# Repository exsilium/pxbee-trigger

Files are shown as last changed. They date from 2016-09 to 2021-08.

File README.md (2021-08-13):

# pxbee-trigger

Programmable XBee Trigger that is ZigBee Home Automation profile compliant. Possible to integrate with [SmartThings](https://www.smartthings.com) Hub v3 or a separate ZigBee / XBee network. Includes a reference hardware design up to 4 channels with a full BOM, perfect for DIYselfers out there.

Used in real life to automate garage / gate automatons.

## Hardware example

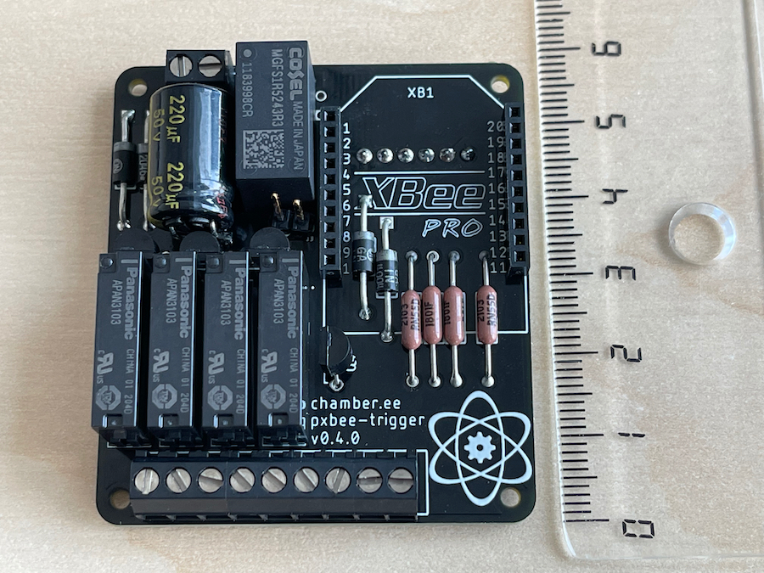
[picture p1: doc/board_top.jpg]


An assembled board without a mounted XBee radio. Metric scale for reference (cm.). Board dimension - 51 x 57 mm.
## Bill of Materials (BOM)

| Designator  | Component | Manufacturer | Quantity | SKU / Part nr. | Spec | Option |
| --- | --- | --- | --- | --- | --- | --- |
| XB1 | [Programmable XBee](https://www.digi.com/products/xbee-rf-solutions/rf-modules/xbee-zigbee#partnumbers) (with RPSMA) | [Digi](https://www.digi.com) | 1 | XBP24CZ7SITB003 | [PDF](http://www.digi.com/resources/documentation/digidocs/pdfs/90002002.pdf) | |
| BR1 | [Bridge Rectifier DF01M](https://www.mouser.ee/ProductDetail/512-DF01M) | [ON Semiconductor](https://www.onsemi.com) | 1 | Mouser No: 512-DF01M | [PDF](https://www.mouser.ee/datasheet/2/308/DF10M-D-1803766.pdf) | |
| C1 (C2) | [Electrolytic Capacitor - Radial 220uF 50V](https://www.mouser.ee/ProductDetail/EEU-FM1H221) | [Panasonic](https://industrial.panasonic.com). | 1-2 | Mouser No: 667-EEU-FM1H221. | [PDF](https://www.mouser.ee/datasheet/2/315/ABA0000C1018-947496.pdf). | |
| PS1 | [DC/DC Isolated Converter Cosel MGFS1R5243R3](https://www.mouser.ee/ProductDetail/436-MGFS1R5243R3) | [Cosel](https://www.coseleurope.eu) | 1 | Mouser No: 436-MGFS1R5243R3 | [PDF](https://www.mouser.ee/datasheet/2/622/SFE_MGFS-1115632.pdf) | |
| Q1,Q2,Q3,Q4 | [Bipolar Transistor BC548BTA](https://www.mouser.ee/ProductDetail/512-BC548BTA) | [ON Semiconductor](https://www.onsemi.com) | 4 | Mouser No: 512-BC548BTA | [PDF](https://www.mouser.ee/datasheet/2/308/BC548-1118644.pdf) | |
| D1,D2,D3,D4 | [Diode 1N4004](https://www.mouser.ee/ProductDetail/863-1N4004RLG) | [ON Semiconductor](https://www.onsemi.com) | 4 | Mouser No: 863-1N4004RLG | [PDF](https://www.mouser.ee/datasheet/2/308/1N4001-D-110363.pdf) | |
| K1,K2,K3,K4 | [General Purpose Relay (APAN3103)](https://www.mouser.ee/ProductDetail/769-APAN3103) | [Panasonic](https://industrial.panasonic.com) | 4 | Mouser No: 769-APAN3103 | [PDF](https://www.mouser.ee/datasheet/2/315/mech_eng_pan-1299258.pdf) | |
| R1,R2,R3,R4 | [Resistor RN55D1801FB14](https://www.mouser.ee/ProductDetail/71-RN55D1801FB14) | [Vishay](https://www.vishay.com) | 4 | Mouser No: 71-RN55D1801FB14 | [PDF](https://www.mouser.ee/datasheet/2/427/cmfmil-109690.pdf) | |
| XB1 | [10 pin header for XBee](https://www.mouser.ee/ProductDetail/855-M22-7131042) | [Harwin](https://www.harwin.com) | 2 | Mouser No: 855-M22-7131042 | [PDF](https://www.mouser.ee/datasheet/2/181/M22-713-1134021.pdf) | |
| J1 | [2 pin Terminal Block (PCB)](https://www.mouser.ee/ProductDetail/538-39501-1002) | [Molex](https://www.molex.com) | 1 | Mouser No: 538-39501-1002 | [PDF](https://www.mouser.ee/datasheet/2/276/0395011002_TERMINAL_BLOCKS-163759.pdf) | A |
| | [2 pin Terminal Plug](https://www.mouser.ee/ProductDetail/538-39500-0002) | [Molex](https://www.molex.com) | 1 | Mouser No: 538-39500-0002 | [PDF](https://www.mouser.ee/datasheet/2/276/0395000002_TERMINAL_BLOCKS-136229.pdf) | A |
| J2 | [9 pin Terminal Block (PCB)](https://www.mouser.ee/ProductDetail/538-39501-1009) | [Molex](https://www.molex.com) | 1 | Mouser No: 538-39501-1009 | [PDF](https://www.mouser.ee/datasheet/2/276/0395011009_TERMINAL_BLOCKS-163629.pdf) | A |
| | [9 pin Terminal Plug](https://www.mouser.ee/ProductDetail/651-1908101) | [Molex](https://www.molex.com) | 1 | Mouser No: 651-1908101 | [PDF](https://www.mouser.ee/datasheet/2/276/0395000009_TERMINAL_BLOCKS-163669.pdf) | A |
| J1 | [2 pin Fixed Terminal Block (PCB)](https://www.mouser.ee/ProductDetail/538-39357-0002) | [Molex](https://www.molex.com) | 1 | Mouser No: 538-39357-0002 | [PDF](https://www.mouser.ee/datasheet/2/276/0393570002_TERMINAL_BLOCKS-227759.pdf) | B |
| J2 | [9 pin Fixed Terminal Block (PCB)](https://www.mouser.ee/ProductDetail/538-39357-0009) | [Molex](https://www.molex.com) | 1 | Mouser No: 538-39357-0009 | [PDF](https://www.mouser.ee/datasheet/2/276/0393570009_TERMINAL_BLOCKS-136250.pdf) | B |
| | [Antenna with RP-SMA Connector](https://www.mouser.ee/ProductDetail/712-ANT-2.4-CW-RAH) | [Linx Technologies](https://linxtechnologies.com) | 1 | Mouser No: 712-ANT-2.4-CW-RAH | [PDF](https://www.mouser.ee/datasheet/2/238/ant-2.4-cw-rah-ccc-1659143.pdf) | |
| JP1 | [6 pin Debug Header](https://www.mouser.ee/ProductDetail/538-22-28-8065) | [Molex](https://www.molex.com) | 1 | Mouser No: 538-22-28-8065 | [PDF](https://www.mouser.ee/datasheet/2/276/0022288065_PCB_HEADERS-159204.pdf) | O |
| J3 | [2 pin Reset Header](https://www.mouser.ee/ProductDetail/Molex/22-28-5027) | [Molex](https://www.molex.com) | 1 | Mouser No: 538-22-28-5027 | [PDF](https://www.mouser.ee/ProductDetail/Molex/22-28-5027) | O |

Standard 3.5 width headers are used. Option **A**) uses pluggable termination; **B**) Fixed screw termination; **O**) Parts are optional and meant for development; Components can easily be switched with other termination blocks or use direct wire soldering.

## Compiling

- On 32bit Linux target, simply: `make`
- On 64bit Linux target:
    - Intall 32bit compatible libraries: `sudo apt-get install lib32stdc++6`
    - `make`
- On MacOS:
    - Install [Docker](https://www.docker.com)
    - `make builddocker`
    - `make dall`

## Firmware

- Output file: `obj/trigger.abs.bin`
- Upload the file via local XMODEM or use Over-the-air upgrade if the current firmware supports it (you can use [pxbee-fwup.js](https://github.com/exsilium/pxbee-fwup.js))
- See further [Programmable XBee documentation](http://xbee-sdk-doc.readthedocs.io)

## Trigger

Send a Unicast ZCL "On" command to trigger the connected relay for 125ms (Relay 1). The state of the switch remains in "Off" state. Broadcast command is ignored by default.

```
Endpoint: 0xEA,
clusterId: 0x0006,
profileId: 0x0104,
command: 0x01
```

## Settings

The following defines can be altered in `custom.h` prior to compilation to change the behavior how the Trigger works:

|  Name | Description | Default |
| ---| --- | --- |
| `PXBEE_TRIGGER_IGNORE_BROADCAST` | When enabled, ignores broadcast commands and reacts only when unicast messages are sent to the specific address (ignores All On/All Off commands). | Enabled |
| `ZCL_MANUFACTURER` | The reported manufacturer string. For SmartThings local execution support without custom device handler, set this to "Leviton". | "PXBee" |
| `ZCL_MODEL` | The reported model string. For SmartThings local execution support without custom device handler, set this to "ZSS-10". | "Trigger" |

### Endpoints

|  Endpoint | Description |
| ---| --- |
| `0xEA` | Relay 1 |
| `0xEB` | Relay 2 |
| `0xEC` | Relay 3 |
| `0xED` | Relay 4 |
| `0xEE` | Auxiliary binary input endpoint |

## License

This project is based on [exsilium/pxbee-blink-led](https://github.com/exsilium/pxbee-blink-led) boilerplate and includes the full [Digi](http://www.digi.com) XBee SDK version 1.6.0 sources.

Includes the necessary build binaries:
```
HI-CROSS+ ANSI-C Compiler for HC08 V-5.0.39, Dec 13 2011
HI-CROSS+ SmartLinker V-5.0.48, Dec 13 2011
HI-CROSS+ Burner V-5.0.16, Dec 13 2011
(c) Copyright Freescale 1987-2010
```

If not otherwise noted, the added code is [BSD licensed](LICENSE).

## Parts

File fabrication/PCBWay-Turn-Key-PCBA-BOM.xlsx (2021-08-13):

 |  |  | PXBee-Trigger PCBA BOM
Item # | *Designator | *Qty | Manufacturer | *Mfg Part # | Description / Value | *Package/Footprint | Type | Your Instructions / Notes
1 | BR1 | 1 | ON Semiconductor | DF01M | Bridge Rectifiers 1.5A Bridge | PDIP-4 | Thru-hole
2 | C1 | 1 | Panasonic | EEU-FM1H221 | Aluminium Electrolytic Capacitors - Radial Leaded 220UF 50V ELECT FM RADIAL | Radial 10mm | Thru-hole | Placement on top! Needs to be mounted higher and with 90 degree angle locating the cap on top of DF01M
3 | PS1 | 1 | Cosel | MGFS1R5243R3 | Isolated DC/DC Converters 1.32W 9-36Vin 3.3V 0.4A PCB SIP6 | 17.0X12.0X8.5mm | Thru-hole
4 | Q1,Q2,Q3,Q4 | 4 | ON Semiconductor | BC548BTA | Bipolar Transistors - BJT NPN 30V 100mA HFE/450 | TO-92-3 Kinked Lead | Thru-hole
5 | D1,D2,D3,D4 | 4 | ON Semiconductor | 1N4004RLG | Rectifiers 400V 1A Standard | DO-41 | Thru-hole
6 | K1,K2,K3,K4 | 4 | Panasonic | APAN3103 | General Purpose Relays 3.0volts 1 Form A PLC Relay | 5.0X20.0X12.5mm | Thru-hole
7 | R1,R2,R3,R4 | 4 | Vishay | RN55D1801FB14 | Metal Film Resistors - Through Hole 1/8watt 1.8Kohms 1% 100ppm | B14 | Thru-hole
8 | XB1 (Left, Right) | 2 | Harwin | M22-7131042 | Headers & Wire Housings 10 PIN SIL VERTICAL GOLD+TIN SOCKET | 10POS | Thru-hole | 2mm pitch
9 | J1 | 1 | Molex | 39357-0002 | Fixed Terminal Blocks 3.5MM FIXED PCB 2P 16-26AWG | 2POS | Thru-hole
10 | J2 | 1 | Molex | 39357-0009 | Fixed Terminal Blocks 3.5MM FIXED PCB 9P 16-26AWG | 9POS | Thru-hole
11 | J3 | 1 | Molex | 22-28-5027 | Headers & Wire Housings KK 100 Hdr Assy Bkwy Bkwy 02 Ckt 30 SGold | 2POS | Thru-hole
12 | JP1 | 1 | Molex | 22-28-8065 | Headers & Wire Housings KK 100 Hdr Assy RA B Bkwy 06 Ckt 30 SGold | 6POS | Thru-hole | Placement on bottom side

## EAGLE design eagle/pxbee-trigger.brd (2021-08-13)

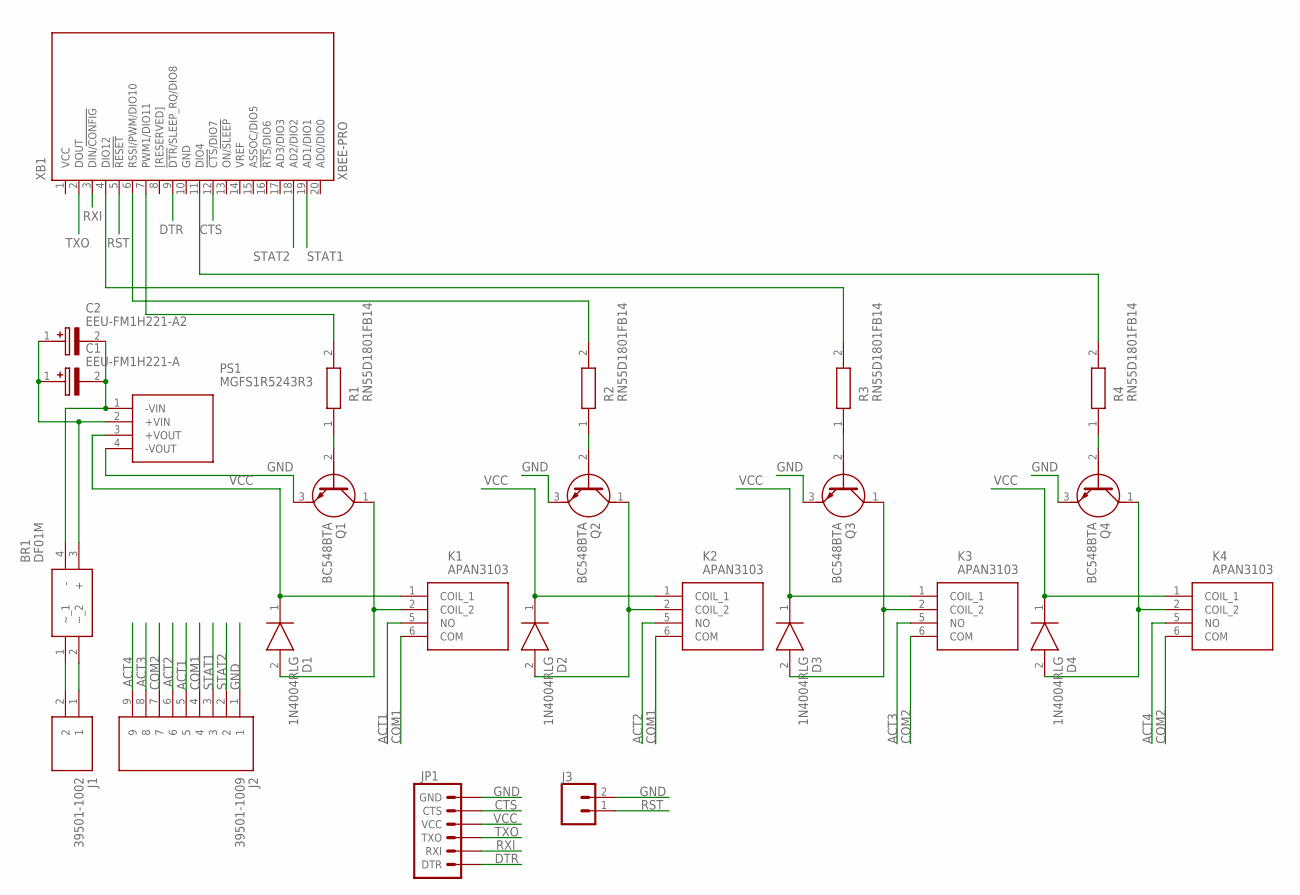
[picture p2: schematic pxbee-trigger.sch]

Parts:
BR1: DF01M; DIP825W114P510L828H330Q4N
C1: EEU-FM1H221-A; CAPANGLED
C2: EEU-FM1H221-A2; CAPANGLED-B
D1, D2, D3, D4: 1N4004RLG; DIOAD1405W86L465D235
J1: 39501-1002; 395011002
J2: 39501-1009; SHDR9W80P0X350_1X9_3290X690X96
J3: CONN_02; 1X02
JP1: 6_PIN_SERIAL_TARGETSILK; 6_PIN_SERIAL_TARGET_SIDE_W_SILK
K1, K2, K3, K4: APAN3103
PS1: MGFS1R5243R3; MGFS1R52415
Q1, Q2, Q3, Q4: BC548BTA
R1, R2, R3, R4: RN55D1801FB14; RESAD1526W69L610D229
XB1: XBEE-PRO

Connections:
ACT1: J2.5, K1.5 (NO)
ACT2: J2.6, K2.5 (NO)
ACT3: J2.8, K3.5 (NO)
ACT4: J2.9, K4.5 (NO)
COM1: J2.4, K1.6 (COM), K2.6 (COM)
COM2: J2.7, K3.6 (COM), K4.6 (COM)
CTS: JP1.P$5 (CTS), XB1.12 (!CTS!/DIO7)
DTR: JP1.P$1 (DTR), XB1.9 (!DTR!/SLEEP_RQ/DIO8)
GND: J2.1, J3.2, JP1.P$6 (GND), PS1.4 (-VOUT), Q1.3 (E), Q2.3 (E), Q3.3 (E), Q4.3 (E), XB1.10 (GND)
unnamed: Q1.2 (B), R1.1
unnamed: Q2.2 (B), R2.1
unnamed: D1.2 (A), K1.2 (COIL_2), Q1.1 (C)
unnamed: D2.2 (A), K2.2 (COIL_2), Q2.1 (C)
unnamed: Q3.2 (B), R3.1
unnamed: D3.2 (A), K3.2 (COIL_2), Q3.1 (C)
unnamed: Q4.2 (B), R4.1
unnamed: BR1.1 (~_1), J1.2
unnamed: BR1.2 (~_2), J1.1
unnamed: D4.2 (A), K4.2 (COIL_2), Q4.1 (C)
unnamed: R1.2, XB1.7 (PWM1/DIO11)
unnamed: R2.2, XB1.6 (RSSI/PWM/DIO10)
unnamed: R3.2, XB1.4 (DIO12)
unnamed: R4.2, XB1.11 (DIO4)
RST: J3.1, XB1.5 (!RESET)
RXI: JP1.P$3 (RXI), XB1.3 (DIN/!CONFIG)
STAT1: J2.3, XB1.19 (AD1/DIO1)
STAT2: J2.2, XB1.18 (AD2/DIO2)
TXO: JP1.P$2 (TXO), XB1.2 (DOUT)
VCC: D1.1 (K), D2.1 (K), D3.1 (K), D4.1 (K), JP1.P$4 (VCC), K1.1 (COIL_1), K2.1 (COIL_1), K3.1 (COIL_1), K4.1 (COIL_1), PS1.3 (+VOUT), XB1.1 (VCC)
VIN+: BR1.3 (+), C1.1 (+), C2.1 (+), PS1.2 (+VIN)
VIN-: BR1.4 (-), C1.2 (-), C2.2 (-), PS1.1 (-VIN)

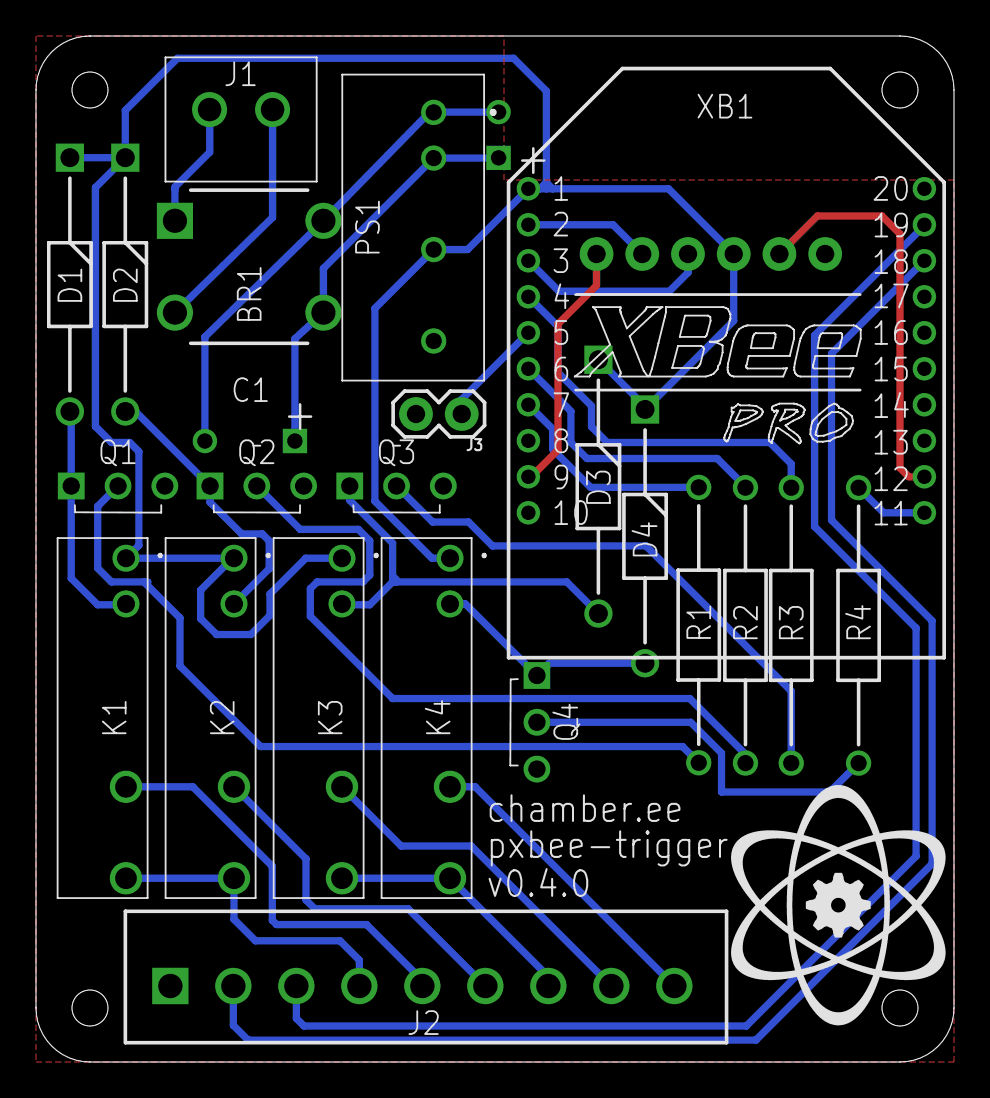
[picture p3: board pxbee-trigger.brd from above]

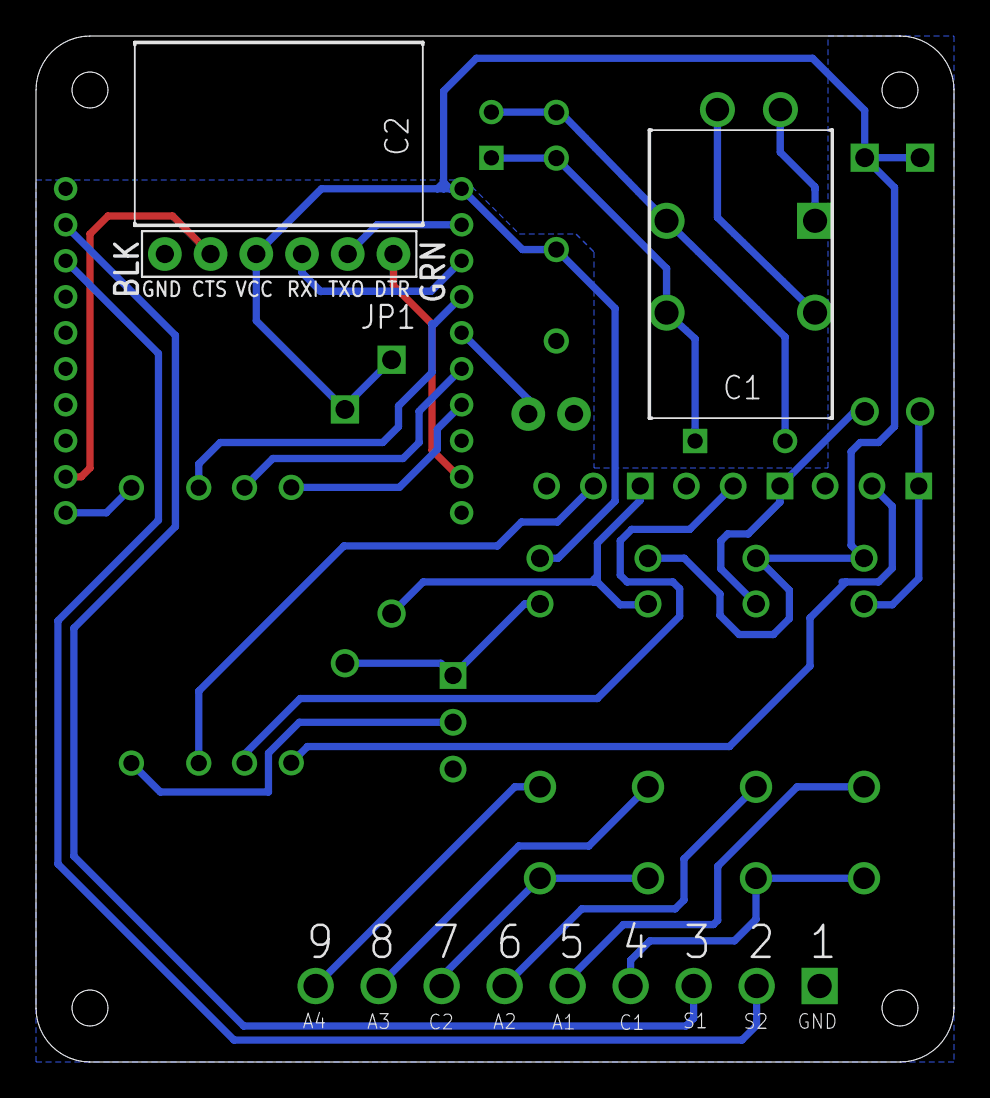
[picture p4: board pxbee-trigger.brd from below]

Board: 2 copper layers, 51.0 x 57.0 mm, 25 parts (3 on the bottom side), 31 nets.

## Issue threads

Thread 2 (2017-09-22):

Trigger works when ZigBee All On is sent

exsilium, 2017-09-22:
When testing OSRAM Lightify ZigBee 4-button switch, which by default has a function to send out "All On" / "All Off" command it was seen that the Trigger also reacted to the On command. As the aim of the trigger is to control gates etc. This should not happen. Ignore broadcast commands and only Trigger when signal is explicitly sent to the device.

https://github.com/exsilium/pxbee-trigger/blob/d4d1ee0b6b15bada5034871f5918d0bb33095e6b/src/main.c#L264

exsilium, 2017-10-25:
Some findings:

- The Lightify ZigBee switch sends the ZCL Frame Control as `0001 0001` using the upper part of the frame control which should be reserved?
- It's possible to detect the broadcast signal via `envelope->options`. The switch broadcast option is sent as `0x301` (0b1100000001)

Closed 2017-10-25.

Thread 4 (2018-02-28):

Trouble connecting to SmartThings

stevenlovegrove, 2018-02-28:
I'm trying to reproduce your results with my SmartThings hub but I'm completely new to both smartthings handlers and zigbee. I followed your instructions to set

#define ZCL_MANUFACTURER    "Leviton"
#define ZCL_MODEL           "ZSS-10"

in custom.h in order to try to avoid having to write a custom handler. I have built and uploaded the new firmware and I am greeted with the devices interactive prompt if I open a serial terminal to it. Is there anything else I need to do to add the device from within my smartthings app? Do I need to initiate pairing or something?

Can you recommend any useful way of debugging zigbee / smartthings?

Thanks again for your help!

exsilium, 2018-02-28:
Hi @stevenlovegrove !

1. SmartThings expects certain XBee settings to have been set:

https://github.com/exsilium/pxbee-trigger/blob/2573c08c45ed26d318066fa75e1fb5bb1953326e/include/custom.h#L9

 you can either do it via XCTU (after putting the radio into Bypass mode) or, as you have connected to the module via serial, you can use the `2` key for *Init additional radio settings* to do that for you. Makes sense to power-cycle the module after the settings have been set.

2. From the SmartThings phone app, press the ´+`  to add new *things*, the ZSS-10 should be found.

stevenlovegrove, 2018-02-28:
Hmm, I'd tried using the 'Init additional radio' previously but that didn't seem to help.

To set the XBee PAN, I assume the easiest way is through XCTU? I tried to use `./fwup -d /dev/... -B` to get into bypass mode, but the tool hangs after writing 'Entering bypass handling!'. If I leave it open then XCTU can't open the port, and if I ctrl-c fwup then XCTU asks me to reset the device, and then when I do it times out.

Also, this is probably a silly question, but how would I discover the PAN of existing devices on my network? Is the PAN likely to be the same as the 'Network Device Id' listed on api.smartthings.com for one of my zigbee devices?

Thanks again for your help on this, I really appreciate it!

exsilium, 2018-02-28:
Ctrl-c from fwup, but when adding to XCTU, add it as a standard non-programmable module. Don't reset the module as it will exit from the bypass. See if that helps.

Previously the PAN ID was available when logging in via https://graph.api.smartthings.com/
Currently I see only 16-bit PAN ID presented there and a channel... I wonder why they changed this.. 🤕

exsilium, 2018-02-28:
Actually the EUI listed, **is** the PAN ID via the https://graph.api.smartthings.com/

exsilium, 2018-03-03:
I just checked the XBee radio settings, and the PanID does not match the EUI listed nor the `${hub.zigbeeId}`. So I currently can't tell from where it would be easy to read the PAN ID that SmartThings creates... :(

exsilium, 2020-07-17:
This is an old and stale issue. I've since migrated the modules from SmartThings Hub v2 to Hub v3 - the only connectivity isssue I had is that the module must be in close proximity to the coordinator. Initial pairing and discovery does not work via routers, even in the node join time is infinite (0xFF). After successful pairing with SmartThings, further links are established within the mesh with other routers. Closing.

Closed 2020-07-17.

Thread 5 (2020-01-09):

Post remarks to PCB fabrication (v0.1.1-pcbfab.1)

exsilium, 2020-01-09:
Dump the Phoenix connectors, 5.08mm is too big, and 2.54mm is too small (no normal screw based termination solutions seem available atm. One option would be to replace the connectors with 3.5mm Molex Eurotype plug which would allow either one-piece or header+plug type of termination. Either way, the connectors seem to be more reasonably priced with stock available.

Proposed to change the following:
- [x] Phoenix Contact - 2 pin Terminal Block (PCB) (5452153) -> Molex 39501-1002 (Alternative one-piece: Molex 39357-0002)
- [x] Phoenix Contact - 8 pin Terminal Block (PCB) (1963599) -> Molex 39501-1008 (Alternative one-piece: Molex 39357-0008)
- [x] Dimension the board 75x75mm, so that it can fit to a small size plastic junction box
- [x] Use 9 pin terminal block and add additional connection for another status/button pin (Molex 39501-1009)

exsilium, 2020-02-04:
A new tag `v0.1.2-pcbfab.1` has been published, but the order cannot be processed yet. International logistics like DHL has suspended orders until 10th of February due to the [coronavirus ourbreak](https://en.wikipedia.org/wiki/2019–20_Wuhan_coronavirus_outbreak)

exsilium, 2020-02-10:
Submitted for review

exsilium, 2020-02-24:
Fabrication completed, waiting for delivery.

Closed 2020-03-11.

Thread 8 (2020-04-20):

Post remarks to PCB fabrication (v0.1.3-pcbfab.1)

exsilium, 2020-04-20:
Prototype run of 5 boards was ordered from PCBWay on 28th of March 2020 with the following parameters. (Gerber project files available and tagged as `v0.1.3-pcbfab.1`
Board type | Single pieces | Panel Way |  
-- | -- | -- | --
Different Designin Panel | 1 | X-out Allowance in Panel |  
Size | 51 x 57 mm | Quantity | 5
Layer | 2 Layers | Material | FR-4: TG130
Thickness | 1.6 mm | Min Track/Spacing | 6/6mil
Min Hole Size | 0.3mm ↑ | Solder Mask | Black
Silkscreen | White | Gold fingers | No
Surface Finish | HASL with lead | "HASL" to "ENIG" | Yes
Via Process | Tenting vias | Finished Copper | 1 oz Cu
Extra pcb product number |   | Additional Options | UL Marking:None

exsilium, 2020-06-08:
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

Closed 2020-06-08.

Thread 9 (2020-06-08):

Update BOM based on v0.1.3 PCB design

exsilium, 2020-06-08:
As continuation from #8, update the Bill of Materials list

exsilium, 2021-03-25:
BOM up-to-date also according to `v0.3.0-pcbfab.1`, Closing

Closed 2021-03-25.

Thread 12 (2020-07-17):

PCB design does not work with 24VAC input

exsilium, 2020-07-17:
One of the goals of the project is to be able to interface the PCB with BFT gate drivers which uses 24VAC for auxiliary devices. The `v0.1.3` PCB design does not work with VAC input due to a missing smoothing capacitor.

The following needs to be fixed:
1. Add a missing smoothing capacitor after the bridge rectifier (needs to be dimensioned)
2. re-check the bridge rectifier for 24VAC as the current DF005M doesn't seem to carry sufficient reverse voltage rating
3. Update the pcb design to `v0.3.0` to reflect the next full release

exsilium, 2021-08-12:
Verified in real life - closing

Closed 2021-08-12.

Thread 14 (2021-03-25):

Logic error in status pin Interrupt service routines

exsilium, 2021-03-25:
The current logic is faulty, does not operate correctly and can cause the XBee module to become unresponsive to external Zigbee communications losing ability to control the automaton connected to the module.

The initial thinking was:
- Have a global variable to keep state of GPIO IRQ ISR (`status_1_InterruptFree`)
- Check if TPM timer has been started (`status_1_TimerSet`)
- Record the present negated value of the GPIO in the Zigbee data structure
- Start a PERIODIC timer and set the global that the Timer is set

https://github.com/exsilium/pxbee-trigger/blob/aab446bc3cbb17c9166789d6ff0d39b4e6ab1de0/src/main.c#L591-L603

- The timer ISR would send the state update message and keep the state (`status_1_SendStatus`)
- The timer would keep running until a contact open state would be reached, in which case another update message would be sent out and the time associated with origan interrupt be terminated

https://github.com/exsilium/pxbee-trigger/blob/aab446bc3cbb17c9166789d6ff0d39b4e6ab1de0/src/main.c#L555-L569

In reality the flow does not work as expected for multiple reasons:
- The default state of the gate automaton is actually contact closed, because the gate remains closed majority of the time
- The timer will remain triggering ISR (`status_1_CheckTimer_irq`)
- On edge cases (due to debounce), an incorrect value may be set to `binaryInput.present_value` which would further break down the logic by sending an incorrect status notification
- It was noted that under real life conditions the module became unresponsive to external ZigBee messaging after certain time had passed. This is possibly due to the excessive processing caused by the ISRs in the MCU

Closed 2021-08-13.

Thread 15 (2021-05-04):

Implement support for GPIO_IRQ_EDGE_BOTH type of ISR

exsilium, 2021-05-04:
Programmable XBee SDK v1.6.0 does not have built in support for detecting and running ISR on both edge slopes.

To be able to address issues in #14 and to be able to make the implementation coded much cleaner, add support for `GPIO_IRQ_EDGE_BOTH` interrupt type.

The implication is that this change will be made in the SDK. Altough this is an unofficial addition - it can be reused in other projects when required.

Closed 2021-08-13.

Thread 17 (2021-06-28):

Get a quote for minimal PCBA service from PCBWay

exsilium, 2021-06-28:
Idea is to request a full PCBA service from PCBWay for the minimal prototype run (5 pcs.). Sourcing components from Mouser.

1. Lead time - slack
2. Parts source - Turn-key
3. Assembly options - TH one-sided
4. Types of solder - Lead-free
5. Stencils - N/A
6. Minimum order - 5
7. Component size - Large
8. Component package - Loose
9. Board dimension - 51 x 57 mm
10. Board shape - Rectangular
11. Board type - Rigid
12. Repair & Rework - N/A

exsilium, 2021-06-29:
Request submitted. Audit in process.

exsilium, 2021-08-12:
This is long overdue but the pricing ended up being following:

| Item | Designator        | Qty | Manufacturer     | Mgf Part #    | Package / Footprint | Unit price 5 sets | 5 sets price |
|------|-------------------|-----|------------------|---------------|---------------------|-------------------|--------------|
|    1 | BR1               |   1 | ON Semiconductor | DF01M         | PDIP-4              | US$0.395          | US$1.98      |
|    2 | C1                |   1 | Panasonic        | EEU-FM1H221   | Radial 10mm         | US$0.965          | US$4.83      |
|    3 | PS1               |   1 | Cosel            | MGFS1R5243R3  | 17.0X12.0X8.5mm     | US$17.075         | US$85.38     |
|    4 | Q1,Q2,Q3,Q4       |   4 | ON Semiconductor | BC548BTA      | TO-92-3 Kinked Lead | US$0.289          | US$5.78      |
|    5 | D1,D2,D3,D4       |   4 | ON Semiconductor | 1N4004RLG     | DO-41               | US$0.210          | US$4.20      |
|    6 | K1,K2,K3,K4       |   4 | Panasonic        | APAN3103      | 5.0X20.0X12.5mm     | US$6.398          | US$127.96    |
|    7 | R1,R2,R3,R4       |   4 | Vishay           | RN55D1801FB14 | B14                 | US$0.428          | US$8.56      |
|    8 | XB1 (Left, Right) |   2 | Harwin           | M22-7131042   | 10POS               | US$1.089          | US$10.89     |
|    9 | J1                |   1 | Molex            | 39357-0002    | 2POS                | US$1.338          | US$6.69      |
|   10 | J2                |   1 | Molex            | 39357-0009    | 9POS                | US$3.590          | US$17.95     |
|   11 | J3                |   1 | Molex            | 22-28-5027    | 2POS                | US$0.245          | US$1.23      |
|   12 | JP1               |   1 | Molex            | 22-28-8065    | 6POS                | US$0.895          | US$4.48      |

Parts Total: US$279.91
PCB Manufacturing, assembly: US$35.09
Shipping charge: US$38.00
Bank fee: US$15.00
Discount: US$-31.00

Order amount total $337.00 USD

Price per unit prior to import tax: **$67.40 USD**

exsilium, 2021-08-12:
Finished product:
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

Closed 2021-08-12.

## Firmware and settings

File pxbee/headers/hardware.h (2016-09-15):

/****************************************************************************
 * Copyright (C) 2011 - 2015 Digi International Inc, All Rights Reserved.
 *
 * This software is provided as instructional material without charge 
 * by Digi International for use by its employees and customers
 * subject to the following terms.
 *
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
 * LIABILITY
 * IN NO EVENT SHALL DIGI INTERNATIONAL BE LIABLE FOR ANY CLAIM, DAMAGES, 
 * OR OTHER LIABILITY, WHETHER IN AN ACTION OF CONTRACT, TORT, OR OTHERWISE, 
 * ARISING FROM, OUT OF, OR IN CONNECTION WITH THE SOFTWARE, OR THE USE 
 * OR OTHER DEALINGS WITH THE SOFTWARE.
 *
 ****************************************************************************/

#ifndef __HARDWARE_H_
#define __HARDWARE_H_

#include <xbee_config.h>
#include <types.h>

/*
 * The xpin_t enumeration encodes the pin capabilities as follows:
 * -Bit 15: determines if the pin is IRQ capable
 * -Bit 14: determines if this pin has an alternative configuration
 * -Bits 13-10: PWM channel (0xf indicates no PWM capable)
 * -Bits 9-6: ADC channel (0xf indicates no ADC capable)
 * -Bits 5-3: Port (A, B, C, D or E)
 * -Bits 2-0: Port Bit (0-7) * 
 */

#define IRQABLE		(1 << 15)
#define HAS_ALT		(1 << 14)
#define PORTBIT_SH	0	/* 3 bits to encode the PORTBIT */
#define PORTBIT_MSK	0x7
#define PORT_SH		3	/* Port shift, 3 bits to encode the PORT */
#define PORT_MSK	0x7
#define ADCCH_SH	6	/* 4 bit to encode the ADC channel */
#define ADCCH_MSK	0xf
#define PWMCH_SH	10	/* 4 bit to encode the ADC channel */
#define PWMCH_MSK	0xf

#define PORT_A		(0 << PORT_SH)
#define PORT_B		(1 << PORT_SH)
#define PORT_C		(2 << PORT_SH)
#define PORT_D		(3 << PORT_SH)
#define PORT_E		(4 << PORT_SH)

#define PORTBIT(a)	((a) << PORTBIT_SH)
#define ADCCH(a)	((a) << ADCCH_SH)
#define NOADC		ADCCH(0xf)
#define PWMCH(a)	((a) << PWMCH_SH)
#define NOPWM		PWMCH(0xf)
#define NOGPIO		(PORT_MSK << PORT_SH)

#ifdef CONFIG_XBEE_THT
/** @ingroup types
 */
/// An enum for manage the pins of the S2B module, this typedef show the possibilities of the pins
typedef enum xpin {
	XPIN_1  = NOPWM | NOADC | NOGPIO,
	XPIN_2  = IRQABLE | NOPWM | ADCCH(5) | PORT_B | PORTBIT(1),
    XPIN_3  = IRQABLE | NOPWM | ADCCH(4) | PORT_B | PORTBIT(0),
    XPIN_4  = PWMCH(4) | NOADC | PORT_B | PORTBIT(4),
    XPIN_5  = NOPWM | NOADC | PORT_A | PORTBIT(5),
    XPIN_6  = PWMCH(11) | NOADC | PORT_C | PORTBIT(5),
    XPIN_7  = IRQABLE | NOPWM | ADCCH(2) | PORT_A | PORTBIT(2),
    XPIN_8  = NOPWM | NOADC | PORT_A | PORTBIT(4),
    XPIN_9  = IRQABLE | NOPWM | NOADC | PORT_D | PORTBIT(5),
    XPIN_10 = NOPWM | NOADC | NOGPIO,
    XPIN_11 = IRQABLE | NOPWM | ADCCH(7) | PORT_B | PORTBIT(3),
    XPIN_12 = PWMCH(6) | NOADC | PORT_C | PORTBIT(0),
    /* ON/SLEEP can not be configured yet with other functionality
     * than IRQ capability for ON/SLEEP support on S2B
     */
#ifndef CONFIG_XBEE_S2B
    XPIN_13 = IRQABLE | PWMCH(3) | ADCCH(1) | PORT_A | PORTBIT(1),
#else
    XPIN_13 = IRQABLE | NOPWM | NOADC | PORT_A | PORTBIT(1),
#endif
    XPIN_14 = NOPWM | NOADC | NOGPIO,
    XPIN_15 = IRQABLE | NOPWM | NOADC | PORT_D | PORTBIT(4),	
    XPIN_16 = IRQABLE | NOPWM | NOADC | PORT_D | PORTBIT(7),		
    XPIN_17 = PWMCH(5) | ADCCH(9) | PORT_B | PORTBIT(5),
    XPIN_18 = IRQABLE | NOPWM | ADCCH(6) | PORT_B | PORTBIT(2),
    XPIN_19 = IRQABLE | NOPWM | ADCCH(3) | PORT_A | PORTBIT(3),		
    XPIN_20 = IRQABLE | PWMCH(0) | ADCCH(0) | PORT_A | PORTBIT(0),		
    XPIN_UNDEF = NOPWM | NOADC | NOGPIO
} xpin_t;
/// \cond 

#define XBEE_MAX_XPIN	20
#define RESET_XPIN		XPIN_5
#define RSSI_XPIN		XPIN_6
#define BKGD_XPIN		XPIN_8
#define SLEEP_RQ_XPIN	XPIN_9
#define ON_SLEEP_XPIN	XPIN_13
#define ASSOC_XPIN		XPIN_15
#define COMMISS_XPIN	XPIN_20

/* Identifiers to enable special pin functionality */
#ifdef ENABLE_RESET_PIN_XPIN_5
#define ENABLE_RESET_PIN
#endif
#ifdef ENABLE_RSSI_PWM_XPIN_6
#define ENABLE_RSSI_PWM
#endif
#ifdef ENABLE_BKGD_PIN_XPIN_8
#define ENABLE_BKGD_PIN
#endif
#ifdef ENABLE_SLEEP_RQ_XPIN_9
#define ENABLE_SLEEP_RQ
#endif
#ifdef ENABLE_ON_SLEEP_XPIN_13
#define ENABLE_ON_SLEEP
#define ENABLE_GPIO_IRQ_XPIN_13
#define GPIO_CFG_IRQ_MODE_13		GPIO_CFG_EDGE_IRQ
#define GPIO_IRQ_LEVEL_EDGE_13		GPIO_IRQ_EDGE_RISE
#define GPIO_IRQ_CFG_PULL_13 		GPIO_IRQ_CFG_PULL_LOW
#endif
#ifdef ENABLE_ASSOCIATION_LED_XPIN_15
#define ENABLE_ASSOCIATION_LED
#endif
#ifdef ENABLE_COMMISSIONING_XPIN_20
#define ENABLE_COMMISSIONING
#endif
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

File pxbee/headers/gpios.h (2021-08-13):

/****************************************************************************
 * Copyright (C) 2010 - 2015 Digi International Inc, All Rights Reserved.
 *
 * This software is provided as instructional material without charge 
 * by Digi International for use by its employees and customers
 * subject to the following terms.
 *
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
 * LIABILITY
 * IN NO EVENT SHALL DIGI INTERNATIONAL BE LIABLE FOR ANY CLAIM, DAMAGES, 
 * OR OTHER LIABILITY, WHETHER IN AN ACTION OF CONTRACT, TORT, OR OTHERWISE, 
 * ARISING FROM, OUT OF, OR IN CONNECTION WITH THE SOFTWARE, OR THE USE 
 * OR OTHER DEALINGS WITH THE SOFTWARE.
 *
 ****************************************************************************/
/** Platform-specific layer provides a consistent MACROS API to upper layers
 *	of the driver.
 *	
 *	@ingroup api_gpios
 *	
 *	@defgroup api_gpios_gpio
 *	
 *	@section macros_gpio Standard GPIO Macros
 *	
 *	The gpio_config() function needs as second parameter a byte containing the 
 *	configuration masks for the GPIO. These masks are defined with macros and 
 *	they are the following:
 *	
 *		- Macros to configure the GPIO \b type:
 * 			- \b GPIO_CFG_INPUT 			: Configures the standard GPIO as 
 * 											  input.
 *			- \b GPIO_CFG_OUTPUT			: Configures the standard GPIO as
 *											  output.
 *	
 *		- Macros to configure the \b pullup resistors:
 *			- \b GPIO_CFG_PULL_UP_DIS		: Disables the GPIO Pull-up resistor.
 *			- \b GPIO_CFG_PULL_UP_EN		: Enables the GPIO Pull-up resistor.
 *	
 *		- Macros to configure the \b slew \b rate:
 *			- \b GPIO_CFG_SLEW_RATE_DIS	: Disables the GPIO slew rate.
 *			- \b GPIO_CFG_SLEW_RATE_EN 	: Enables the GPIO slew rate.
 *	
 *		- Macros to configure the \b drive \b strength:
 *			- \b GPIO_CFG_DRV_STR_LOW		: Configures the drive strength to low.
 *			- \b GPIO_CFG_DRV_STR_HIGH 		: Configures the drive strength to high.
 *	
 *	Usage example:
 *	@code gpio_config(XPIN_7, GPIO_CFG_INPUT | GPIO_CFG_PULL_UP_EN | GPIO_CFG_SLEW_RATE_EN | GPIO_CFG_DRV_STR_LOW);
 *	@endcode
 *	@warning	It is recommended not to use these macros, they are used by 
 *				the XBee Project Smart Editor of the XBee extensions.
 *	
 *	@ingroup api_gpios
 *	
 *	@defgroup api_gpios_irq
 *	
 *	@section macros_irq IRQ Macros 
 *	
 *	The gpio_config_irq() function needs as second and third parameters the 
 *	detection and activation modes to configure the IRQ. These parameters 
 *	are defined with macros and they are the following:
 *	
 *		- Macros to configure the \b detection \b mode of the IRQ: 
 *			- \b GPIO_CFG_LEVEL_IRQ 		: Configures the detection mode as
 *											  level - \b 0.
 *			- \b GPIO_CFG_EDGE_IRQ			: Configures the detection mode as
 *											  edge - \b 1.
 *	
 *		- Macros to configure the \b active \b edge (when the detection 
 *		  mode is configured as \b edge):
 *			- \b GPIO_IRQ_EDGE_BOTH			: Select fall and rise edge - \b 2.
 *			- \b GPIO_IRQ_EDGE_RISE 		: Select the rise-edge mode - \b 1.
 *			- \b GPIO_IRQ_EDGE_FALL 		: Select the fall-edge mode - \b 0.
 *	
 *		- Macros to configure the \b active \b level (when the detection 
 *		  mode is configured as \b level):
 *			- \b GPIO_IRQ_LEVEL_HIGH 		: Select the high-level mode - \b 1.
 *			- \b GPIO_IRQ_LEVEL_LOW 		: Select the low-level mode - \b 0.
 *	
 *	Usage example:
 *	@code gpio_config_irq(XPIN_7, GPIO_CFG_LEVE_IRQ, GPIO_IRQ_LEVEL_HIGH);
 *	@endcode
 *	@warning	It is recommended not to use these macros, they are used by 
 *				the XBee Project Smart Editor of the XBee extensions.
 *
 ***************************************************************************/

#ifndef __GPIO_H_
#define __GPIO_H_

#include <types.h>
#include <hardware.h>


#define GPIO_CFG_INPUT				(0 << 0)
#define GPIO_CFG_OUTPUT				(1 << 0)
#define GPIO_CFG_PULL_UP_DIS		(0 << 1)
#define GPIO_CFG_PULL_UP_EN			(1 << 1)
#define GPIO_CFG_SLEW_RATE_DIS		(0 << 2)
#define GPIO_CFG_SLEW_RATE_EN		(1 << 2)
#define GPIO_CFG_DRV_STR_LOW		(0 << 3)
#define GPIO_CFG_DRV_STR_HIGH		(1 << 3)

#define GPIO_CFG_LEVEL_IRQ			0
#define GPIO_CFG_EDGE_IRQ			1

#define GPIO_IRQ_EDGE_BOTH			(2)
#define GPIO_IRQ_EDGE_RISE			(1)
#define GPIO_IRQ_EDGE_FALL			(0)
#define GPIO_IRQ_LEVEL_HIGH			(1)
#define GPIO_IRQ_LEVEL_LOW			(0)
#define GPIO_IRQ_CFG_PULL_NONE		(0)
#define GPIO_IRQ_CFG_PULL_LOW		(1)
#define GPIO_IRQ_CFG_PULL_HIGH		(2)
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

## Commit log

2016-09-15 Bootstrapping from pxbee-blink-led (d77c995)
2016-09-15 RELAY and relayTimer components added; naming
    - Project target renamed to trigger
2016-09-27 Blink led/relay on teh Grove Xbee Carrier
2016-10-02 Custom endpoint, profile and cluster
    - Playing with the TPM1 timer
2016-10-16 Syntax error fix, relayTimer now actually turns of the relay
2016-10-16 Short readme added with BOM and instructions for use
2017-07-04 Refactoring for some niceties
    - Print operating PAN ID
    - Init additional radio settings
    - Adding debug output to 0x0006 cluster handler
2017-07-06 Removing thew frame_control magic number
2018-01-20 Additional comments added and readme update
    - Clarification on how to join the device as a switch without custom device handler in SmartThings by reporting itself as Leviton / ZSS-10 device
2020-01-07 4 channel relay PCB design sent in for fabrication
    - First version for prototyping
    - Autodesk Eagle backup files added to gitignore
    [pxbee-trigger.brd, pxbee-trigger.sch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]
2020-01-17 Change of connector elements, smaller dimensions
    - Change from Phoenix contact to 3.5mm step Molex Eurotype connectors
    - Dimension the board to fit inside a small plastic conjunction box 75x75mm
    - Still work in progress (WIP)
    - Addresses fabrication remarks in #5
    [pxbee-trigger.brd, pxbee-trigger.sch]
2020-01-17 Board routed; Updated parts library
    - Freed pin 20, using pin 4 for gate/door status input
    - Addresses findings in #5
    [pxbee-trigger.brd, pxbee-trigger.sch]
2020-01-17 One airwire network detected; brd corners chopped
    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
    [pxbee-trigger.brd]
2020-01-23 Board dimension changes
    - Dimensioned to 75x75mm
    - 9 pin terminal block used to gain one more status pin
    - Parts library updated (removed unused parts, added new ones)
    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
    [pxbee-trigger.brd, pxbee-trigger.sch]
2020-02-04 PCB Board changes
    - Ready for fabrication v0.1.2-pcbfab.1
    - New pin assignment from XBee side to accommodate GPIO interrupt usage
    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
    [pxbee-trigger.brd, pxbee-trigger.sch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]
2020-02-21 Initial commit to support multiple endpoints and relays
    This is a work in progress to support new design with multiple relay channels.
2020-03-27 Shrinking the pcb design to 51x64mm
    - Addressing findings in #6
    - Eagle upgrade to 9.6.0
    - WIP
    [pxbee-trigger.brd, pxbee-trigger.sch]
2020-03-27 Further shrinkin the pcb size, new format: 51x57mm
    - Addresses findings in #6
    [pxbee-trigger.brd]
2020-03-27 PCB layout fine tuning and fabrication prep
    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
    [pxbee-trigger.brd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]
2020-06-05 Added startup check for STATUS pin states
2020-06-12 Optimized printf usage
    - During experimentation ran into issue of exhausting APP_ROM space. The overuse of printf is contributing to the problem.
    - Relies more on hex_dump() and puts()
2020-06-18 Binary Input cluster read attribute; improvements
    - Relays are all reset on timer experitation
    - On/cluster handles multiple endpoints
    - MFG Specific flags removed
    - Bug fixes
2020-06-30 Change in irq logic for status pins; relay_2 fixed
    - The realisation that the interrupt is and can only be configured one way (Edge fall). We start a periodic timer to detect returning to normal state.
    - Relay 2 was not functioning correctly because the pin configuration was incorrectly set as input
2020-06-30 Debug output added for contact open (status_2 pin)
2020-07-17 Update BOM, fixes #9
2020-07-30 Added capacitors for fixing #12
    - Version of the PCB updated to v0.3.0
    [pxbee-trigger.brd, pxbee-trigger.sch]
2020-07-30 UART header added for easier debugging
    - Fixes #13
    [pxbee-trigger.brd, pxbee-trigger.sch]
2020-07-30 Change CTS routing on PCB
    - Further contributes to #13
    [pxbee-trigger.brd]
2020-07-30 Gerber files updated for fabrication
    [pxbee-trigger.brd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]
2021-03-19 Bridge rectifier upgrade; XBee reset header
    - [Parts] Bridge rectifier upgraded from DF005 to DF01, previous part was underdimensioned
    - [SCH,BRD] Added J3 pinout for XBee Reset
    - [BRD] Version bumped to v0.4.0
    [pxbee-trigger.brd, pxbee-trigger.sch]
2021-03-25 POM update
    - Added capacitor
    - Upgraded Bridge Rectifier
2021-03-25 Add serialpass mode, main menu change, status pins
    - Serialpass mode that can be easily accessed with the S option’
    - Removal of B (sysapp banner) from the main menu as it clashes with the Bypass shortcut from the bootloader menu (easier for debbugging purposes)
    - Swapped the status pins as in the physical design, order changes
    [serialpass.c]
2021-04-26 Status pin corrected in comment
2021-05-03 Fix comment on pin assignment for status pins
2021-05-04 Support for GPIO_IRQ_EDGE_BOTH interrupt type - Allow gpio configuration with edge value of 2 (0b10) - Extend kbiedg parameters to uint16 to keep 2 bits per interrupt slot - Call ISR on both slopes w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
    [gpios.c, gpios.h]
2021-06-01 Improved status pin logic - New implementation around BOTH edge ISR #15 - Watchdog resets added to limit triggering - Fixes #14
2021-06-01 BOM update for optional dev parts
2021-06-29 Minor changes to BRD; PCBA BOM; Gerber updates
    - Minor parts and silkscreen modifications for cleanup
    - Added PCBWay PCBA Bom for turnkey solution quote #17
    - Cam processed gerber fabrication files for v0.4.0 version of the board
    [PCBWay-Turn-Key-PCBA-BOM.xlsx, pxbee-trigger.brd, pxbee-trigger.sch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]
2021-06-30 Added designator to the BOM list
2021-08-12 Add mounting file #17
2021-08-12 Update to main README
    - Added reference hardware picture
    - Reduced the role of SmartThings as it’s not a major integration point going forward
    - Endpoints described
2021-09-16 Comments on mapping endpoints with relays

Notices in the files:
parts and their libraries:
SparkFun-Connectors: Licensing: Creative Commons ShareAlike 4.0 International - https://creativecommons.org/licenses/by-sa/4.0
